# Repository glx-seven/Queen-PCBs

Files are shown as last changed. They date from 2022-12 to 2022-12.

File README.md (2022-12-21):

# Queen-PCBs
These are some Blinky-LED pendants I made a while ago. 

The main components are:
* BQ25570 energy harvesting controller
* KXOB25-05X3F mini solar cell
* MAL219691153E3 4F super-cap (probably has to be replaced with something else due to availability)
* PIC16LF18346-E/GZ (QFN20) MCU (if you're using 1.8V turn off the brown-out detection to make it run properly)

The programming pins match the PICKIT debugger, so you can stick some pogo-pins in the connector and hold it onto the pins to flash th firmware.
I did also upload the MPLAB-X project files for the firmware, it's not very good or complex tho, it just blinks some LEDs.

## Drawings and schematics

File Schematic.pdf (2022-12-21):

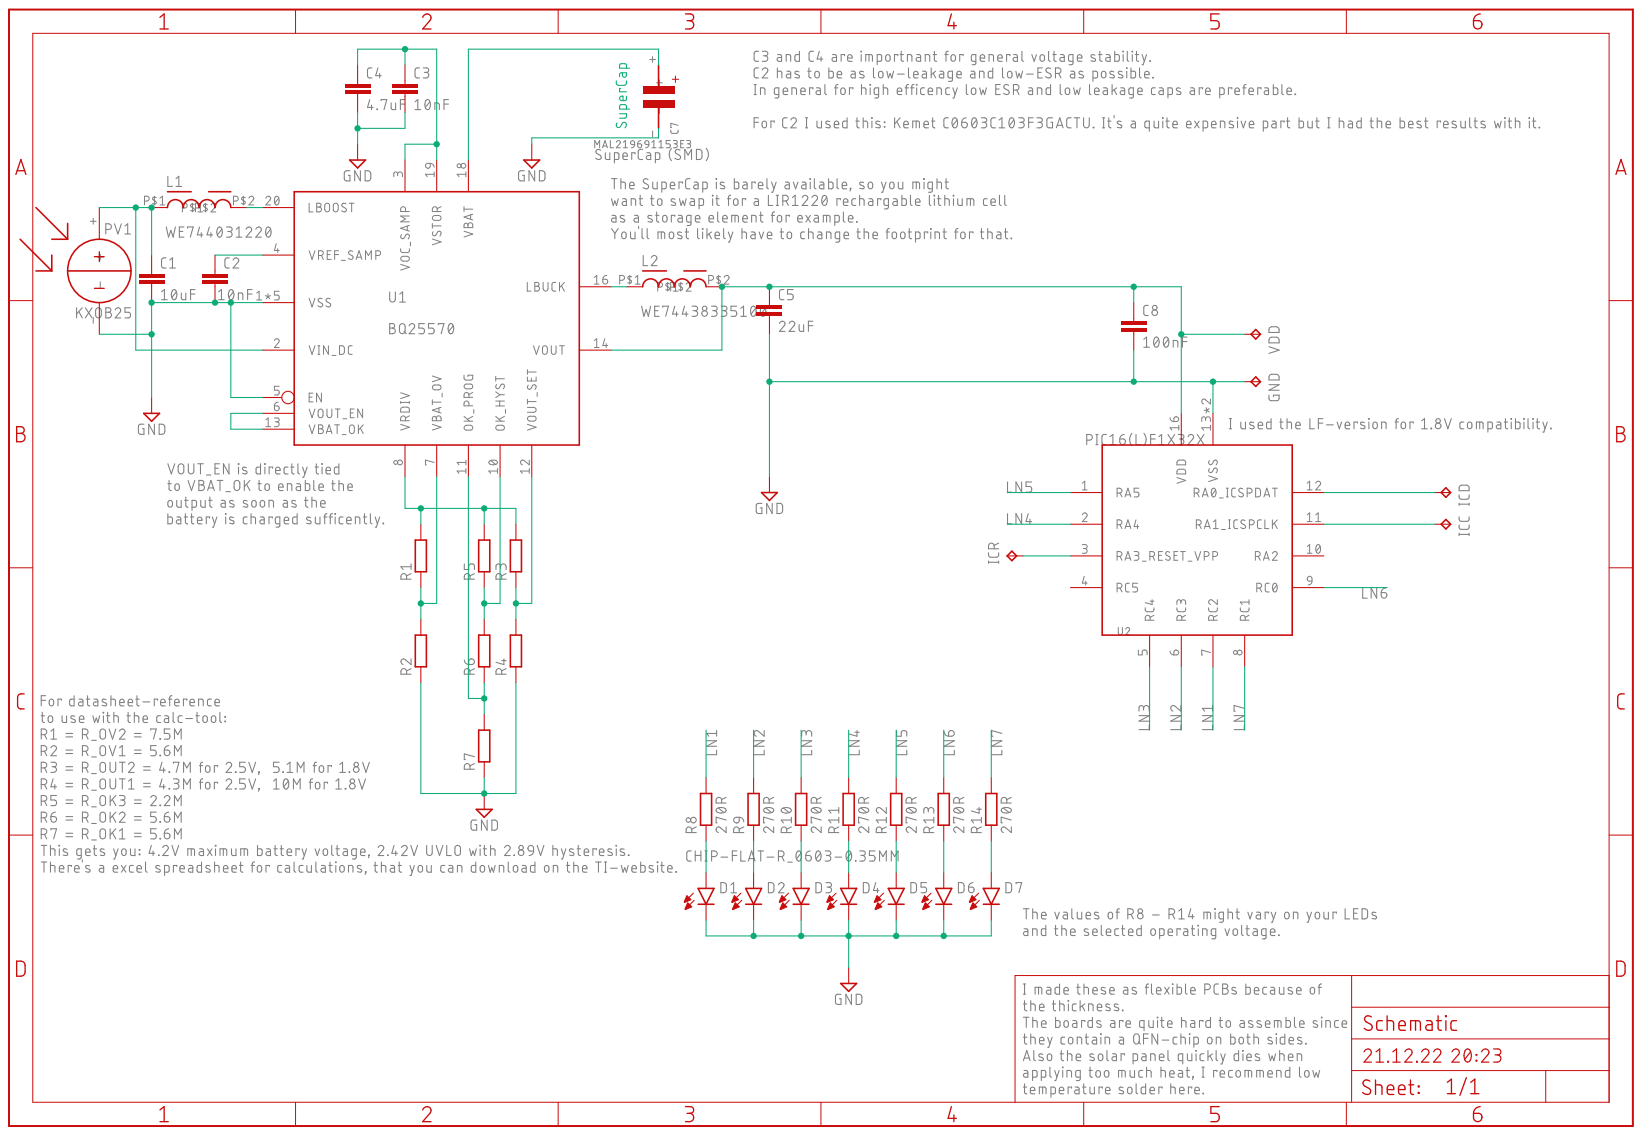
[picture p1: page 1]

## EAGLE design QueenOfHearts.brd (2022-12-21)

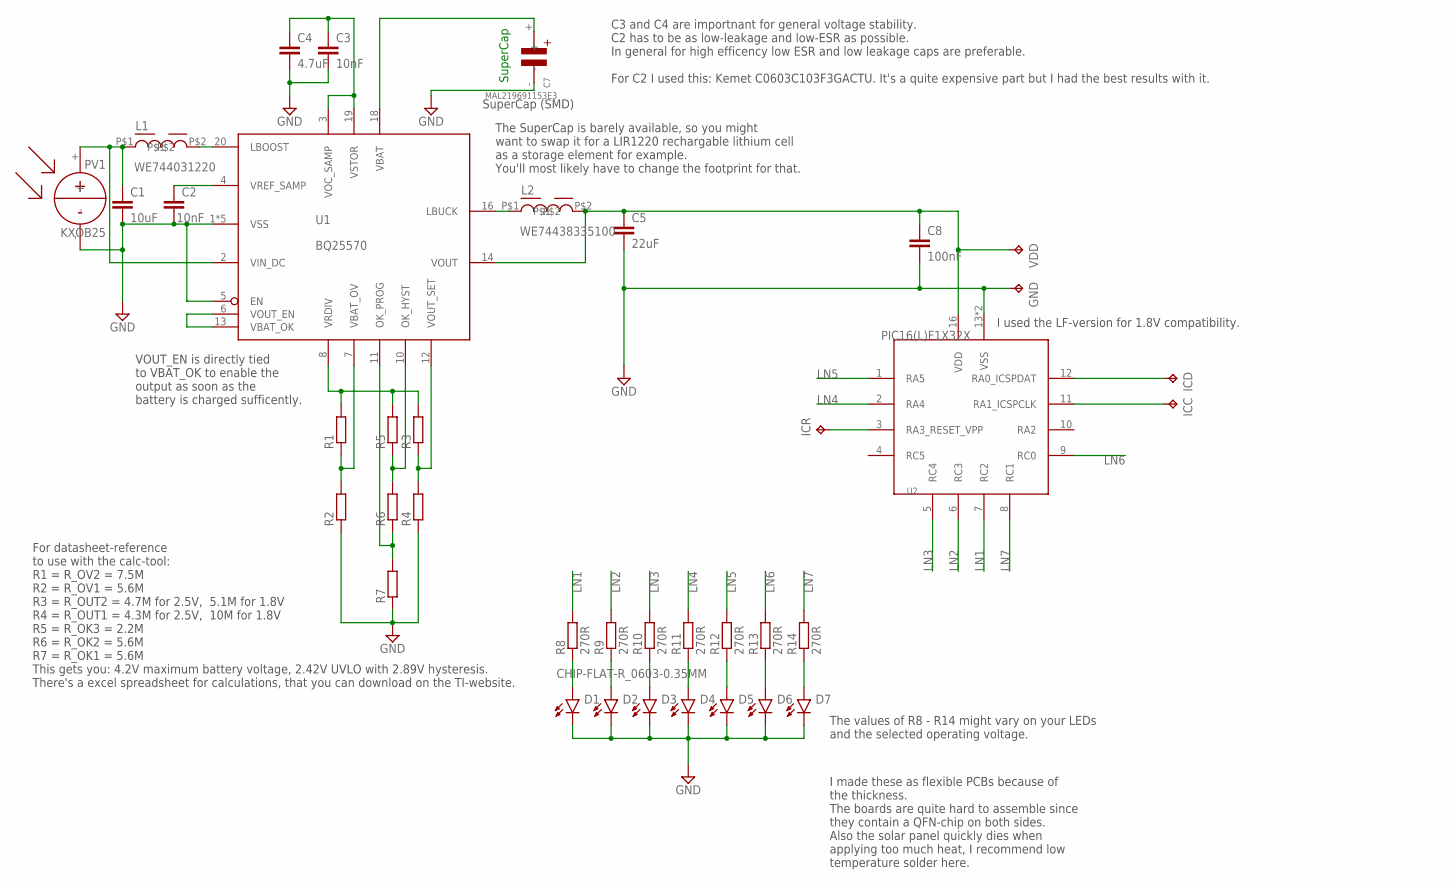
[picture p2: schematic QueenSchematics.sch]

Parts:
C1: 10uF; C0603K
C2, C3: 10nF; C0603K
C4: 4.7uF; C0603K
C5: 22uF; C0603K
C7: MAL219691153E3; MAL219691153E2
C8: 100nF; C0603K
D1, D2, D3, D4, D5, D6, D7: CHIP-FLAT-R_0603-0.35MM; LEDC1608X35N
GND: TPTP06SQ; TP06SQ
ICC: TPTP06SQ; TP06SQ
ICD: TPTP06SQ; TP06SQ
ICR: TPTP06SQ; TP06SQ
L1: WE744031220
L2: WE74438335100
PV1: KXOB25
R1, R2, R3, R4, R5, R6, R7: R-EU_R0603; R0603
R8, R9, R10, R11, R12, R13, R14: 270R; R0603
U1: BQ25570; QFN50P350X350X90-21T205N
U2: PIC16(L)F1X32X; QFN65P400X400X50-17T260N
VDD: TPTP06SQ; TP06SQ

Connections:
GND: C1.2, C2.2, C3.2, C4.2, C5.2, C7.-, C8.2, D1.C, D2.C, D3.C, D4.C, D5.C, D6.C, D7.C, GND.TP, PV1.-, R2.1, R4.1, R7.1, U1.1 (VSS), U1.5 (EN), U1.9 (VSS), U1.15 (VSS), U1.17 (VSS), U1.21 (VSS), U2.13 (VSS), U2.17 (VSS)
LN1: R8.2, U2.7 (RC2)
LN2: R9.2, U2.6 (RC3)
LN3: R10.2, U2.5 (RC4)
LN4: R11.2, U2.2 (RA4)
LN5: R12.2, U2.1 (RA5)
LN6: R13.2, U2.9 (RC0)
LN7: R14.2, U2.8 (RC1)
unnamed: L1.P$2, U1.20 (LBOOST)
unnamed: C1.1, L1.P$1, PV1.+, U1.2 (VIN_DC)
unnamed: C2.1, U1.4 (VREF_SAMP)
unnamed: L2.P$1, U1.16 (LBUCK)
unnamed: C3.1, C4.1, U1.3 (VOC_SAMP), U1.19 (VSTOR)
unnamed: U1.6 (VOUT_EN), U1.13 (VBAT_OK)
unnamed: C5.1, C8.1, L2.P$2, U1.14 (VOUT), U2.16 (VDD), VDD.TP
unnamed: C7.+, U1.18 (VBAT)
unnamed: R1.1, R2.2, U1.7 (VBAT_OV)
unnamed: R5.1, R6.2, U1.10 (OK_HYST)
unnamed: R3.1, R4.2, U1.12 (VOUT_SET)
unnamed: R6.1, R7.2, U1.11 (OK_PROG)
unnamed: ICR.TP, U2.3 (RA3_RESET_VPP)
unnamed: ICD.TP, U2.12 (RA0_ICSPDAT)
unnamed: ICC.TP, U2.11 (RA1_ICSPCLK)
unnamed: D1.A, R8.1
unnamed: D2.A, R9.1
unnamed: D3.A, R10.1
unnamed: D4.A, R11.1
unnamed: D5.A, R12.1
unnamed: D6.A, R13.1
unnamed: D7.A, R14.1
VRDRV: R1.2, R3.2, R5.2, U1.8 (VRDIV)

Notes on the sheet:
For datasheet-reference to use with the calc-tool: R1 = R_OV2 = 7.5M R2 = R_OV1 = 5.6M R3 = R_OUT2 = 4.7M for 2.5V, 5.1M for 1.8V R4 = R_OUT1 = 4.3M for 2.5V, 10M for 1.8V R5 = R_OK3 = 2.2M R6 = R_OK2 = 5.6M R7 = R_OK1 = 5.6M This gets you: 4.2V maximum battery voltage, 2.42V UVLO with 2.89V hyster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
SuperCap
SuperCap (SMD)
C3 and C4 are importnant for general voltage stability. C2 has to be as low-leakage and low-ESR as possible. In general for high efficency low ESR and low leakage caps are preferable. For C2 I used this: Kemet C0603C103F3GACTU. It's a quite expensive part but I had the best results with it.
VOUT_EN is directly tied to VBAT_OK to enable the output as soon as the battery is charged sufficently.
The SuperCap is barely available, so you might want to swap it for a LIR1220 rechargable lithium cell as a storage element for example. You'll most likely have to change the footprint for that.
I used the LF-version for 1.8V compatibility.
The values of R8 - R14 might vary on your LEDs and the selected operating voltage.
I made these as flexible PCBs because of the thickness. The boards are quite hard to assemble since they contain a QFN-chip on both sides. Also the solar panel quickly dies when applying too much heat, I recommend low temperature solder here.

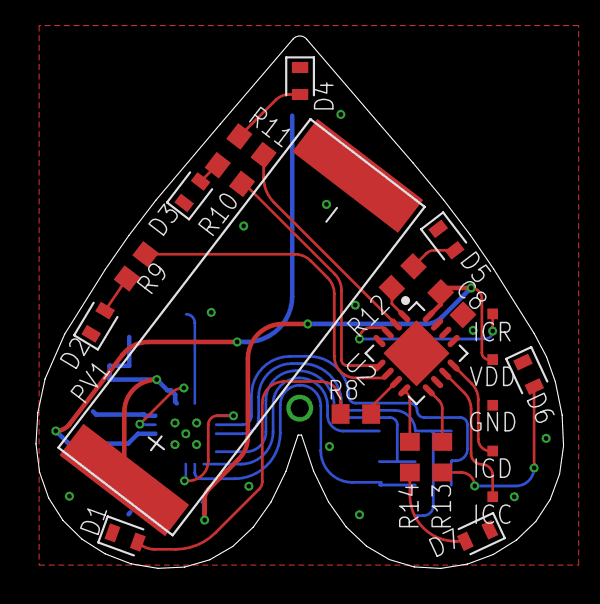
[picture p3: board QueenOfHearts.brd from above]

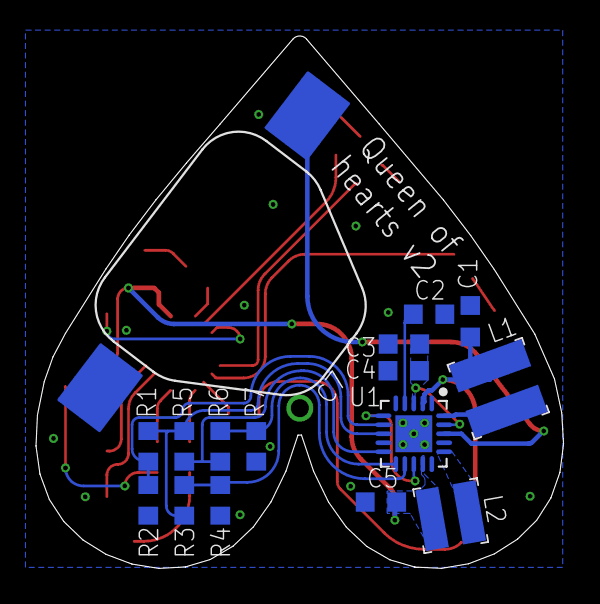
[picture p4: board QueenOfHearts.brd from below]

Board: 2 copper layers, 29.3 x 29.6 mm, 38 parts (16 on the bottom side), 31 nets.
